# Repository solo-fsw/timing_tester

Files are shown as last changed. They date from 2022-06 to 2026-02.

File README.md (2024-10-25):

# Timing Tester

**Protocol commands**
| Event | Command (decimal)	| Note |
| --- | --- | --- |
| MYINFO |	80	|  |
| PING	| 81	|  |
| RESETTESTER	| 90	|  |
| TESTINGFINISHED	| 91	|  |
| DISPLAYTESTSETUP| 100	|  |
| AUDIOTESTSETUP	| 101 |  |
| SRBOXTESTSETUP	| 102	|  |
| MARKER|109	|  |
| STARTDISPLAYTEST	|110	|  |
| STARTAUDIOTEST	| 111	|  |
| STARTSRBOXTEST | 112	|  |
| STOPTESTER	| 115	|  |
| DUMPDISPLAYDATA	| 48	|  |
| DUMPAUDIODATA	| 151	|  |
| DUMPSRBOXDATA	| 152	|  |

# Timing Tester standalone 
<br/>

**Description**<br/>
The timingtester standalone is a easy to use tool for validating the monitor timing of your stimulus.
It's a drop in replacement for the [Usbparmarker](https://researchwiki.solo.universiteitleiden.nl/xwiki/wiki/researchwiki.solo.universiteitleiden.nl/view/Hardware/Markers%20and%20Events/UsbParMarker/) so no need to change your experiment. Future release it will also be possible to dropin replace the Eva.

**How to use**<br/>
If you have used the [Eprime](https://github.com/solo-fsw/eprime_package_markers), [OpenSesame](https://github.com/solo-fsw/opensesame_plugin_markers) or [Python](https://github.com/solo-fsw/python-markers) package for the Usbparmaker it's as simple to unplug the Usbparmarker and plugin the timingtester.
Hold the tester in the middle of the screen and start your script. On the display of the timingtester the test result will be displayed.
On the display you will see at the left upper corner the last measurement. V is for video, A for audio but this is not implement yet.
In the upper right corner is the last marker value is shown.

For correct timing is important that you change your slide from dark to light to activate the lightsensor. After timing testing you can always set the screen color back to the desired color.

If you are not using one of our packages for the Usbparmarker you have to look up yourself the comport in the windows devicemanager and change this in your script.

**What is a correct response time**<br/>
That's hard to say and depends on the stimules software used , hardware and your script.
Minimum response time is depending on you refresh rate. For example a 60Hz monitor has a frame duratione of 1 sec / 60Hz = 16ms. Measuring half way the screen wil give an ideal reponse of 8ms.
As seen in the example below the rest of the system eats up 3ms and the total response time wil be 11ms.
This test is done in E-prime setting the marker in the onset.
If you are in doubt, please contact labsupport the help you testing or give you advise to get the timing better.

**Advanced use**<br/>
The timingtester standalone can be placed in command mode by (re)opening the com port at 2400Baud.
The following commands are supported.
| Event | Command | Note |
| --- | --- | --- |
| MYINFO |	V	|  |
| PING	| P	|  |
| RESETTESTER	| R	|  |

Timingtester

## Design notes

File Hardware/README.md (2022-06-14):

# Hardware
This folder will contain the Timing Tester's firmware and PCB source files.

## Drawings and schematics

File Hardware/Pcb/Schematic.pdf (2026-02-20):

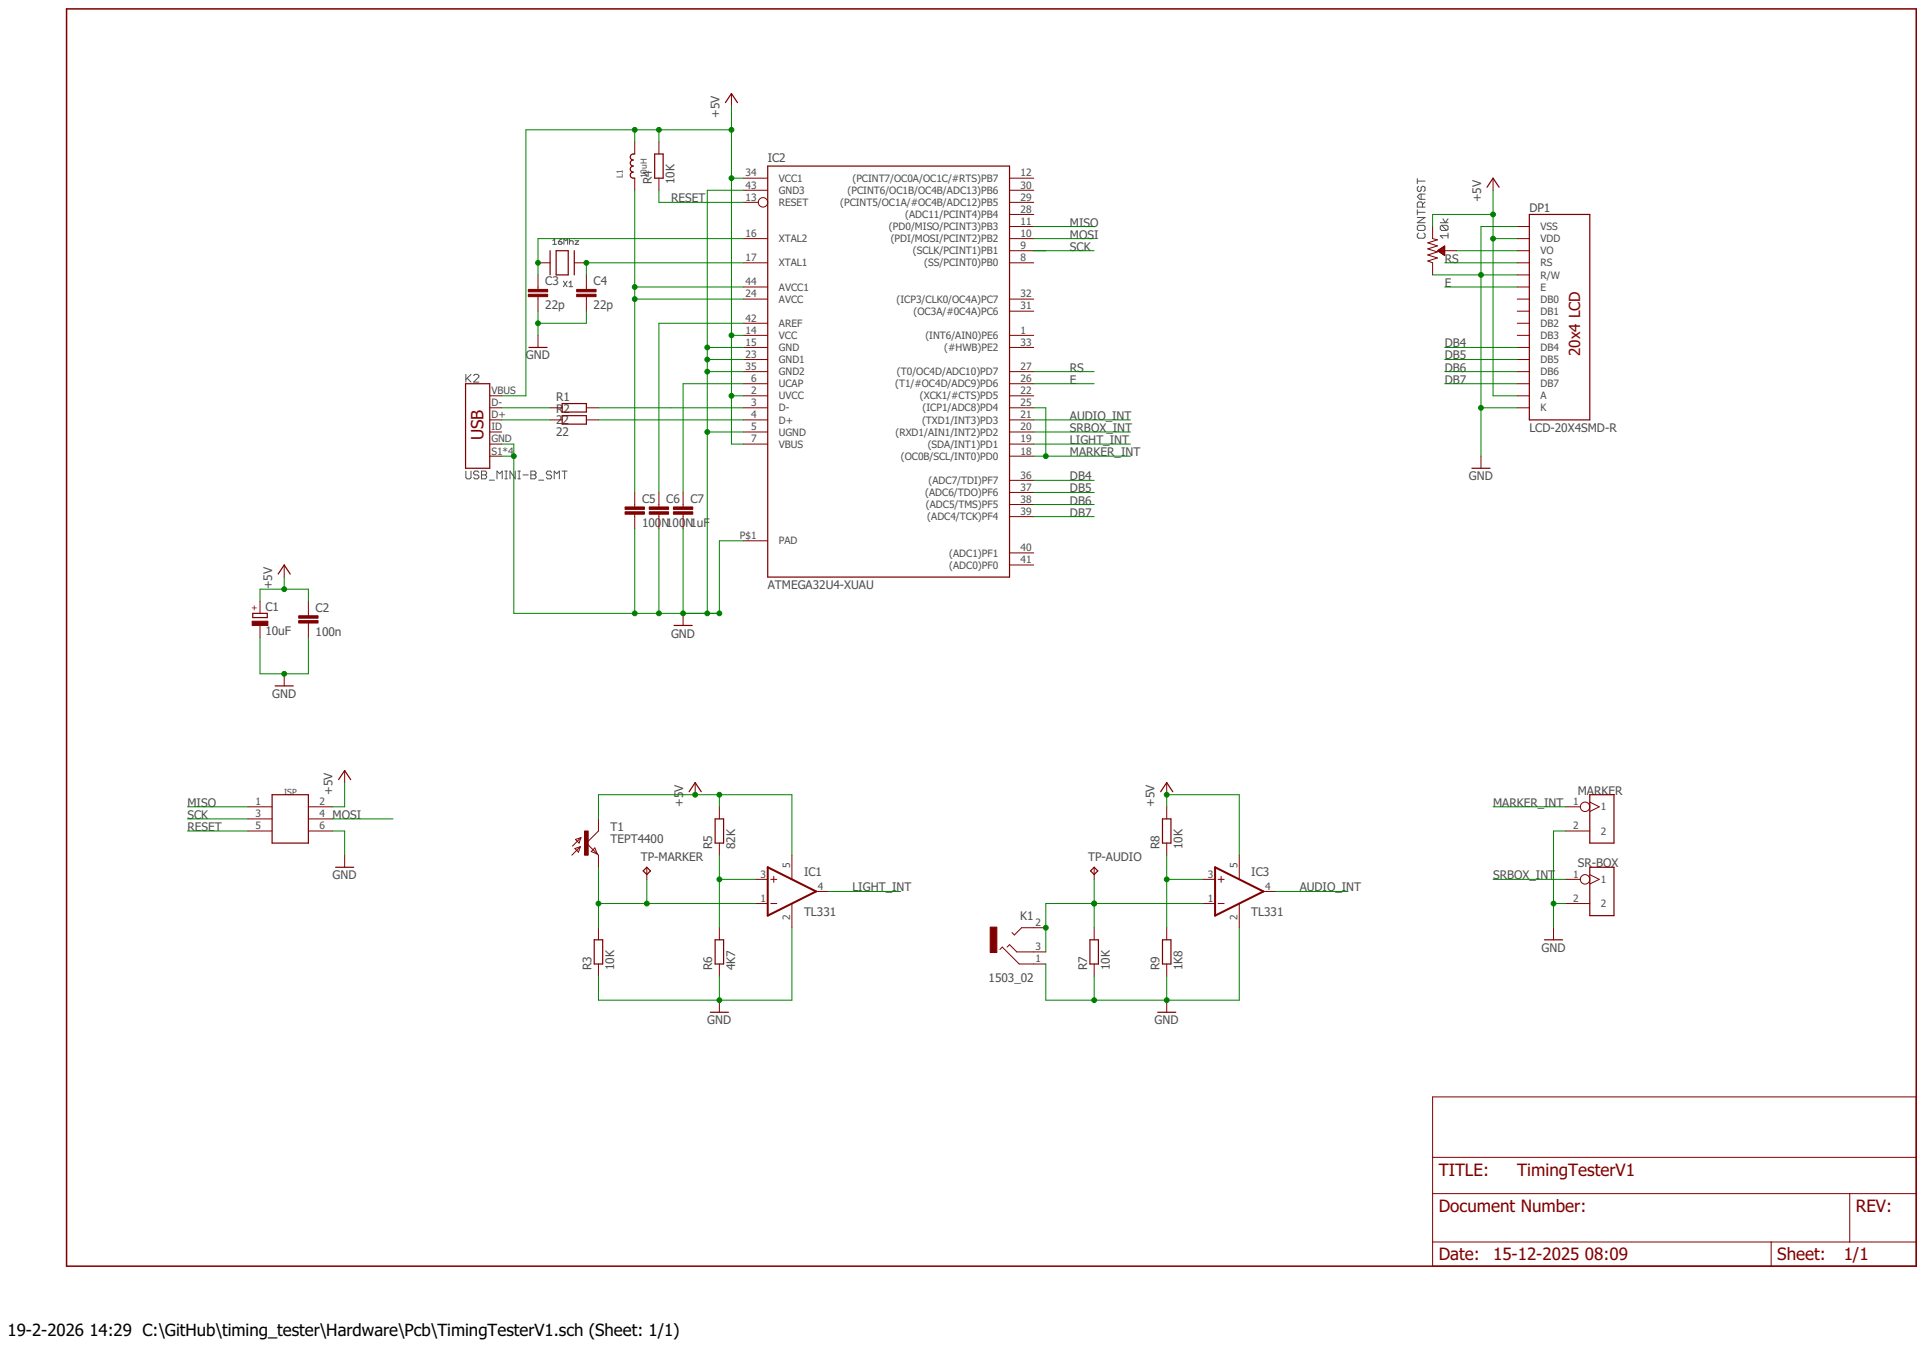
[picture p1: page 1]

Document Number: | REV:

Date: 15-12-2025 08:09 | Sheet: 1/1

19-2-2026 14:29 C:\GitHub\timing_tester\Hardware\Pcb\TimingTesterV1.sch (Sheet: 1/1)

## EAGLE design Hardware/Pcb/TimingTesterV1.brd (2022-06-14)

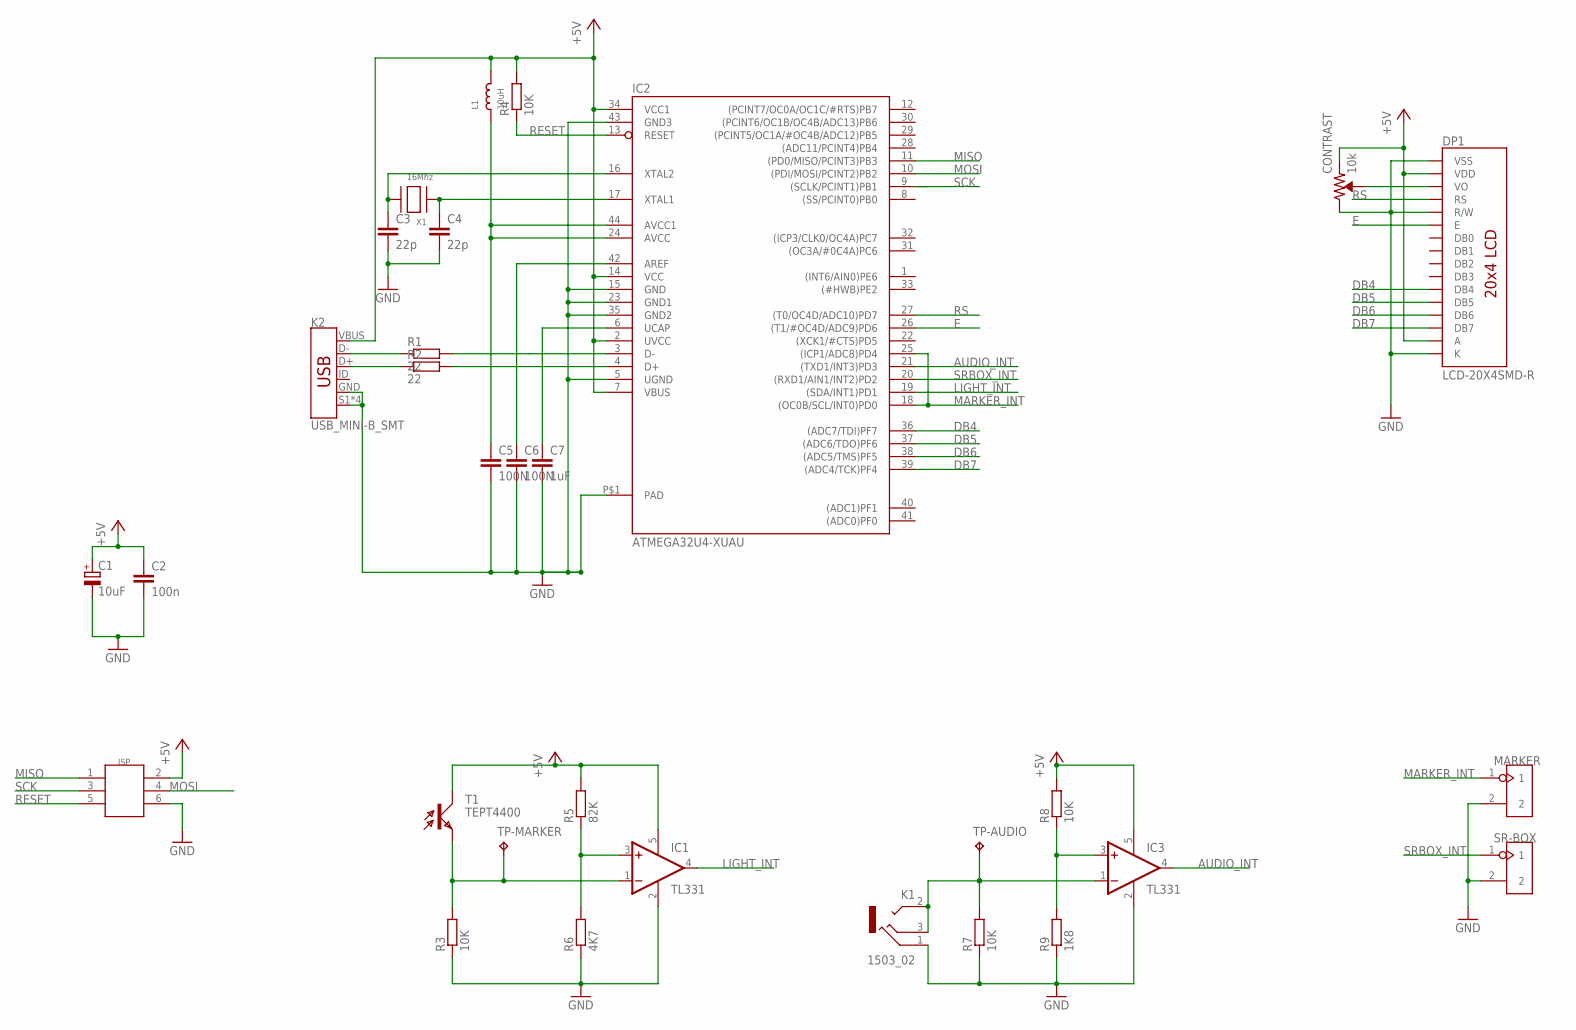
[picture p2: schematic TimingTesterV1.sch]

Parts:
C1: 10uF; R/2012-12R
C2: 100n; C0805
C3, C4: 22p; C0805; FARNELL 1759489
C5, C6: 100N; C0805
C7: 1uF; C0805
CONTRAST: 10k; TRIMPOT-SMD-TC33X; FARNELL 1689863
DP1: LCD-20X4SMD-R; LCD-20X4-SMD
IC1, IC3: TL331; DBV-R-PDSO-G5; FARNELL 1470409
IC2: ATMEGA32U4-XUAU; TQFP44-PAD
ISP: HEADER-2X3P-SMD; 2X3P-2.54-SMD; FARNELL 9689567
K1: 1503_02
K2: USB_MINI-B_SMT; USB-MINIB; FARNELL 1753806
L1: 10uH; 0805; FARNELL 2215650
MARKER: HEADER-2PSMD; 2P-2.54-SMD
R1, R2: 22; M0805
R3, R7, R8: 10K; R0603
R4: 10K; M0805
R5: 82K; R0603
R6: 4K7; R0603
R9: 1K8; R0603
SR-BOX: HEADER-2PSMD; 2P-2.54-SMD
T1: TEPT4400; BPX81-SMD
TP-AUDIO: TPTP20R; TP20R
TP-MARKER: TPTP20R; TP20R
X1: 16Mhz; NX5032; FARNELL 2467791

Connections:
+5V: C1.+, C2.2, CONTRAST.3 (CCW), DP1.2 (VDD), DP1.15 (A), IC1.5 (V+), IC2.2 (UVCC), IC2.7 (VBUS), IC2.14 (VCC), IC2.34 (VCC1), IC3.5 (V+), ISP.2, K2.VBUS, L1.2, R4.2, R5.2, R8.2, T1.C
AUDIO_INT: IC2.21 ((TXD1/INT3)PD3), IC3.4 (OUT)
DB4: DP1.11 (DB4), IC2.36 ((ADC7/TDI)PF7)
DB5: DP1.12 (DB5), IC2.37 ((ADC6/TDO)PF6)
DB6: DP1.13 (DB6), IC2.38 ((ADC5/TMS)PF5)
DB7: DP1.14 (DB7), IC2.39 ((ADC4/TCK)PF4)
E: DP1.6 (E), IC2.26 ((T1/#OC4D/ADC9)PD6)
GND: C1.-, C2.1, C3.2, C4.2, C5.2, C6.2, C7.2, CONTRAST.1 (CW), DP1.1 (VSS), DP1.5 (R/W), DP1.16 (K), IC1.2 (GND), IC2.5 (UGND), IC2.15 (GND), IC2.23 (GND1), IC2.35 (GND2), IC2.43 (GND3), IC2.P$1 (PAD), IC3.2 (GND), ISP.6, K1.1, K2.GND, K2.S1 (SHIELD), K2.S2 (SHIELD), K2.S3 (SHIELD), K2.S4 (SHIELD), MARKER.2, R3.1, R6.1, R7.1, R9.1, SR-BOX.2
LIGHT_INT: IC1.4 (OUT), IC2.19 ((SDA/INT1)PD1)
MARKER_INT: IC2.18 ((OC0B/SCL/INT0)PD0), IC2.25 ((ICP1/ADC8)PD4), MARKER.1
MISO: IC2.11 ((PD0/MISO/PCINT3)PB3), ISP.1
MOSI: IC2.10 ((PDI/MOSI/PCINT2)PB2), ISP.4
unnamed: K2.D-, R1.1
unnamed: K2.D+, R2.1
unnamed: IC3.1 (-IN), K1.2, K1.3, R7.2, TP-AUDIO.TP
unnamed: C5.1, IC2.24 (AVCC), IC2.44 (AVCC1), L1.1
unnamed: IC3.3 (+IN), R8.1, R9.2
unnamed: CONTRAST.2 (WIPER), DP1.3 (VO)
unnamed: IC1.1 (-IN), R3.2, T1.E, TP-MARKER.TP
unnamed: IC1.3 (+IN), R5.1, R6.2
unnamed: IC2.3 (D-), R1.2
unnamed: IC2.4 (D+), R2.2
unnamed: C6.1, IC2.42 (AREF)
unnamed: C3.1, IC2.16 (XTAL2), X1.P$2
unnamed: C7.1, IC2.6 (UCAP)
unnamed: C4.1, IC2.17 (XTAL1), X1.P$1
RESET: IC2.13 (RESET), ISP.5, R4.1
RS: DP1.4 (RS), IC2.27 ((T0/OC4D/ADC10)PD7)
SCK: IC2.9 ((SCLK/PCINT1)PB1), ISP.3
SRBOX_INT: IC2.20 ((RXD1/AIN1/INT2)PD2), SR-BOX.1

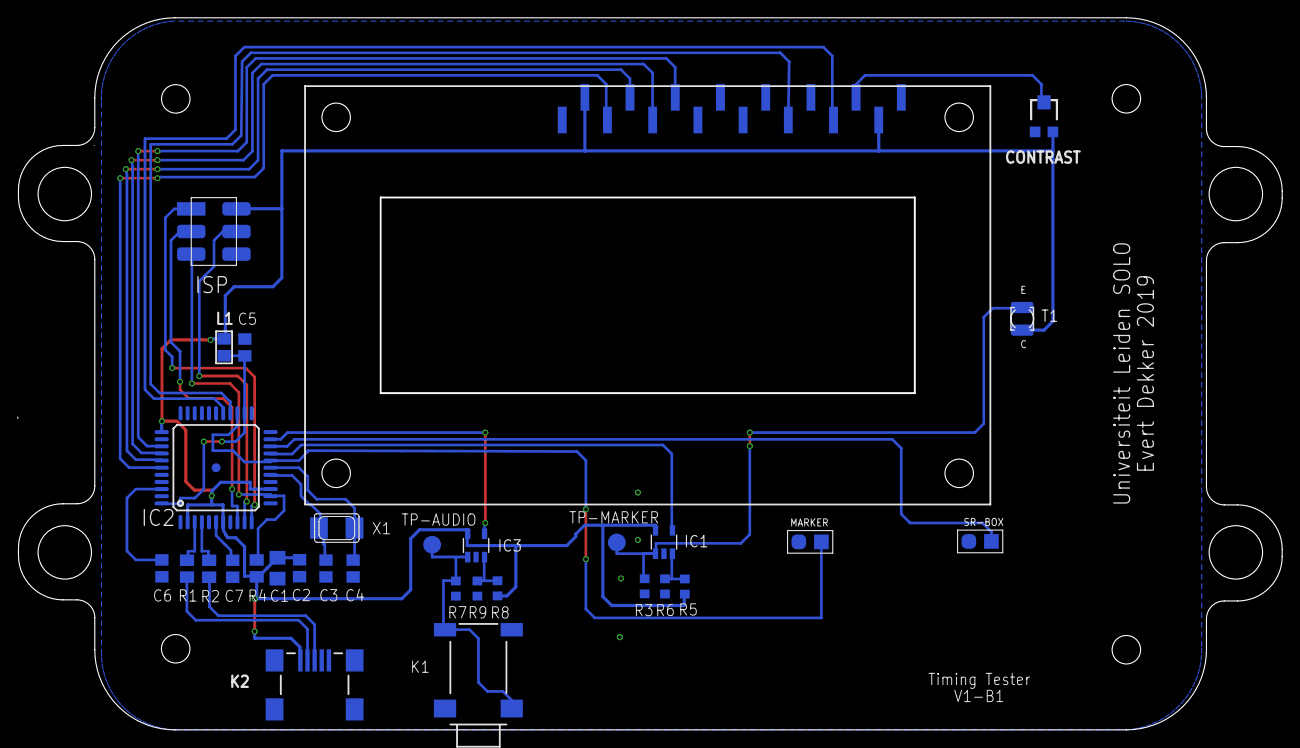
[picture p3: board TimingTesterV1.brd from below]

Board: 2 copper layers, 142.0 x 80.0 mm, 31 parts (30 on the bottom side), 30 nets.

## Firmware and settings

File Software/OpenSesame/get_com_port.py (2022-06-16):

from init_and_close_serial_device import init_serial_device
from init_and_close_serial_device import close_serial_device


def get_port(device_name):
    # Finds the com port address of UsbParMarker or SignalGenerator
    # Note, to find the com port address of the SignalGenerator, the signal_generator module is necessary
    # and to find the com port address of the UsbParMarker, the usb_par_marker module is necessary

    # Input: device_name = 'UsbParMarker' or 'SignalGenerator'
    # Output: com_ports = the com port address(es) to which the serial device is connected.

    # Get serial port addresses
    import serial.tools.list_ports
    ports = serial.tools.list_ports.comports()

    # init:
    port_names = []
    com_ports = []

    # Loop through ports and collect port names:
    for port, desc, hwid in sorted(ports):
        print("{}: {} [{}]".format(port, desc, hwid))
        port_names.append(port)

    # when devices are found, get their actual name
    if len(port_names) != 0:

        if device_name == 'UsbParMarker':

            from usb_par_marker import send_command

            # loop through ports
            for port in port_names:

                # Open port with baudrate of 4800 to be able to get the name of the device:
                ser_device = init_serial_device(port, 4800, 1)

                if type(ser_device) == str:
                    continue

                # Ping the device:
                data = send_command(ser_device, 'P')
                print('data: ' + str(data))

                # Check if UsbParMarker is found:
                if 'UsbParMarker' in data:
                    com_ports.append(port)
                    print('UsbParMarker found')

                # close port
                close_serial_device(ser_device)

        elif device_name == 'SignalGenerator':

            # import module signal_generator
            from signal_generator import send_pulse_train

            # loop through ports
            for port in port_names:

                # open port wth baudrate 4800 (note that the signal_generator uses a baudrate of 115200 normally)
                ser_device = init_serial_device(port, 4800, 2)

                if type(ser_device) == str:
                    continue

                # send pulse and get data
                data = send_pulse_train(ser_device, current=0, ton=1, toff=1, repeat=1)
                print('data: ' + str(data))
                # If the data contains 'Serial', 'Ver' and 'samples' it is assumed we are dealing with a SignalGenerator
                if 'Serial' in data and 'Ver' in data and 'samples':
                    com_ports.append(port)

                # close port
                close_serial_device(ser_device)

    if len(com_ports) == 0:
        com_ports = 'FAKECOM'
    elif len(com_ports) == 1:
        com_ports = com_ports[0]

    return com_ports


# # Test code:
# com_ports_usbparmar = get_com_port('UsbParMarker')
# print('com_ports_usbparmar: ' + str(com_ports_usbparmar))
# com_ports_siggen = get_com_port('SignalGenerator')
# print('com_ports_siggen: ' + str(com_ports_siggen))

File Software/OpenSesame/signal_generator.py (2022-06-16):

def send_pulse_train(sig_gen, current, ton, toff, repeat):
    # Sends a pulse train.

    # Input: - sig_gen = the signal generator serial device (which is outputted when using init_serial_port)
    #        - current = the current in mA
    #        - ton = on time of the pulse in ms
    #        - toff = off time of the pulse in ms
    #        - repeat = number of times the pulse is repeated

    # Output: data (dict) with keys:
    # When no error occurred:
    # - Ver = signal generator version
    # - Serial = serial number of the signal generator
    # - samples = number of samples
    # When the number of samples <= 100:
    # - current = array with measured current in mA (length of array is the number of samples)
    # - voltage = array with measured voltage in volt (length of array is the number of samples)
    # When the number of samples > 100:
    # - MaxCurrent = maximum value of the measured current in mA
    # - MinCurrent = minimum value of the measured current in mA
    # - MaxVolt = maximum value of the measured voltage in volt
    # - MinVolt = minimum value of the measured voltage in volt
    # When one of the values does not meet the requirements or when another error occurs:
    # - Error# = error number
    # - Error = error message

    # NOTE: for more information see the Signal Generator documentation

    # NOTE: when a FakeSerial object with port FAKECOM is passed, a fake data dict with the following values is
    # returned:
    # - Ver = 99
    # - Serial = Fake Signal Generator
    # - samples = repeat
    # - current = 0
    # - voltage = 0

    # NOTE: when communication with the signal generator fails, the output is a string with an error message

    import serial
    import json

    # When the com port address is FAKECOM a fake data dict is created.
    if sig_gen.port == 'FAKECOM':
        data = {
            "Ver": '99',
            "Serial": 'Fake Signal Generator',
            "samples": repeat,
            "current": 0,
            "voltage": 0
        }

        # Wait for the duration of the pulse: (ton + toff) * repeat
        import time
        pulse_duration_sec = ((ton + toff) * repeat) / 1000
        time.sleep(pulse_duration_sec)

        return data

    else:

        try:
            # Write to port (type: bytes)
            pulse_info = "{current:" + str(current) + \
                         ",Ton:" + str(ton) + \
                         ",Toff:" + str(toff) + \
                         ",repeat:" + str(repeat) + \
                         "}\n"

            sig_gen.write(pulse_info.encode())

            # Get data (readline reads a line until line feed '\n', or until the timeout specified when opening the port
            # is reached)
            raw_json_data = sig_gen.readline()
            json_data = raw_json_data.decode('utf-8')
            try:
                data = json.loads(json_data)
            except:
                data = 'Error, no data'

            return data

        # Capture serial communication error
        except serial.serialutil.SerialException:
            return "ERROR: pulse not sent"


# # Test code:
# import init_and_close_serial_device
# sig_gen = init_and_close_serial_device.init_serial_device('COM4')
# data = send_pulse_train(sig_gen, current=0, ton=1, toff=1, repeat=1)
# print(data)
# init_and_close_serial_device.close_serial_device(sig_gen)

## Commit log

2024-10-25 Added sample task
2025-12-15 Changed device name
2026-02-20 Added schematic pdf

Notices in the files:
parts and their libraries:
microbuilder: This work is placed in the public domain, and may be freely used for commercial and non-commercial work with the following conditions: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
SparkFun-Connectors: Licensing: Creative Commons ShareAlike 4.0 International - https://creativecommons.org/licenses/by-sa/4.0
